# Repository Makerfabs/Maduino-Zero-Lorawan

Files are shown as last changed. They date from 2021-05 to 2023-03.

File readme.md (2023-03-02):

# Maduino Zero Lorawan

```c++
/*
Version:		V1.3
Author:			Vincent
Create Date:	2021/5/19
Note:
		V2.0:Change for Ra08
		V1.3:Change Wiki Link
		V1.2:Add Maduino Zero Lorawan Change Frequence.docx
		V1.1:Add At command explain.
*/
```



[toc]

# Makerfabs

[Makerfabs home page](https://www.makerfabs.com/)

[Makerfabs Wiki](https://wiki.makerfabs.com/)

# Maduino Zero Lorawan
## Intruduce

Product Link ：[Maduino Zero LoRaWAN](https://www.makerfabs.com/maduino-zero-lorawan.html) 

Wiki Link :  [Maduino Zero LoRaWAN Node](http://wiki.makerfabs.com/Maduino_Zero_LoRaWAN_Node.html) 

Maduino Zero LoRaWan is a solution based on ATSAMD21G18 MCU and LoRaWAN module Ra-08H. The LoRaWAN module Ra-08H is based on the ASR6501 chip, it integrated the LoRa radio transceiver, LoRa modem, and 32-bit RISC MCU, to support LoRa modulation mode and (G) FSK modulation mode. Maduino LoRaWan acts as a LoRaWAN node to transmit/receive the local data to the network by connecting LoRaWAN Gateway. With this module, users are easy to prototype LoRaWAN projects easily in few hours.

## Feature

- ATSAMD21G18, 32-Bit ARM Cortex M0+
- Interface: I2C/SPI/UART/18*GPIO
- With super anti-interference ability, it can work normally in complex interference environment.
- Minimum receiving sensitivity: -137dBm (SF=12/BW=125KHz)
- Maximum transmit power +21dBm
- Working frequency: (Ra-07) 410mhz ~ 525mhz (default), (Ra-07h) 803mhz ~ 930mhz (default)
- Power supply voltage input: 3.3V
- Transmitting working current: 107mA (full load power consumption)
- Receive working current: 6mA
- Sleep current: 3uA

### Front:

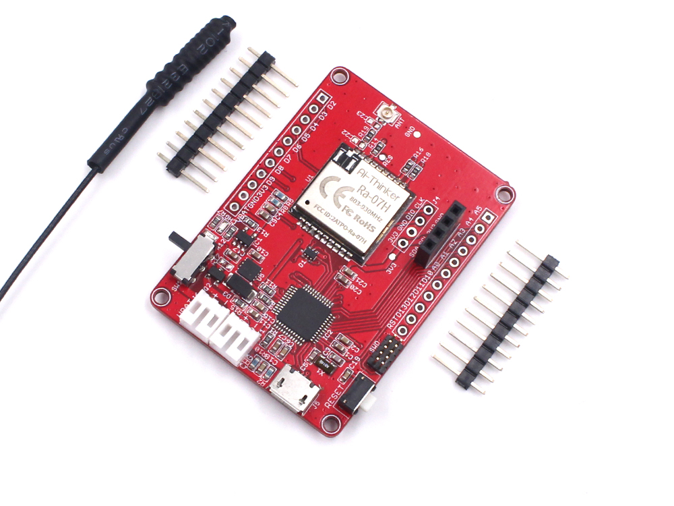
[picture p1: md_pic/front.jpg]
front


### Back:
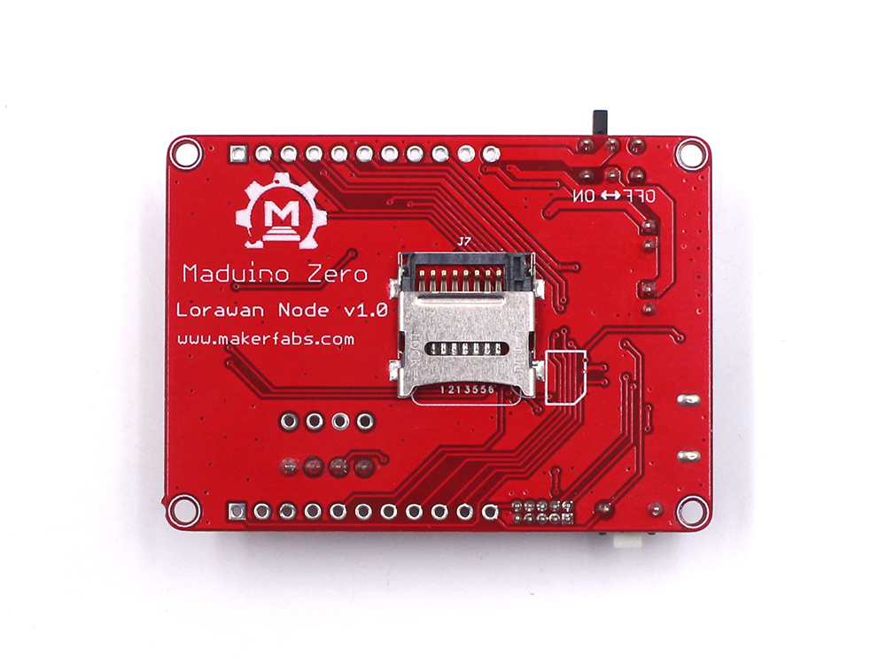
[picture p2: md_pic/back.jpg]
back


# Example

## V2.0 Change Frequence

The module supports 868MHz and 915MHz Lorawan communication, but requires upload different firmware.

**You must need  Makerfabs Down tools or USB to TTL tools**

[MakerFabs CP2104 USB2UART](https://www.makerfabs.com/cp2104-usb-to-serial-converter.html)

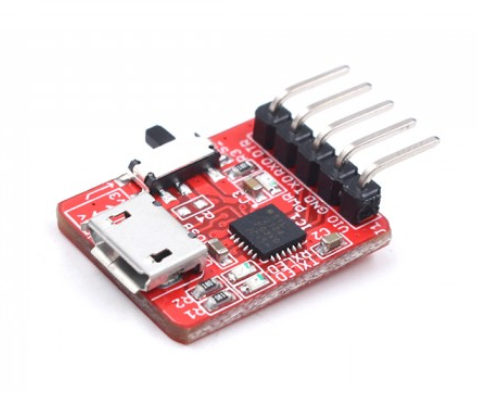
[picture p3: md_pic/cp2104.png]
cp2104


1, Open firmware_update_tool/ TremoProgrammer_v0.8.exe

2, Select firmware you need.

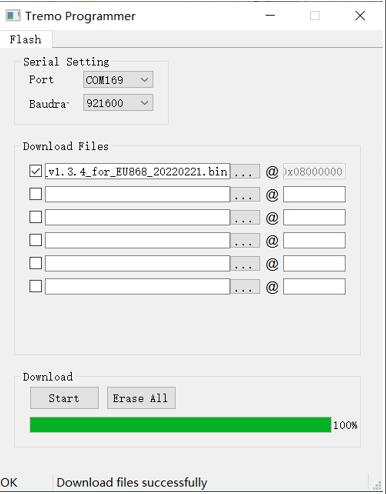
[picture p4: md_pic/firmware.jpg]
firmware


3, Connect MakerFabs CP2104 USB2UART to Maduino Zero Lorawan.

| USB2UART | Maduino Zero Lorawan |
| --- | --- |
| VCC | 3.3V |
| GND | GND |
| TX | CLK |
| RX | DIO |

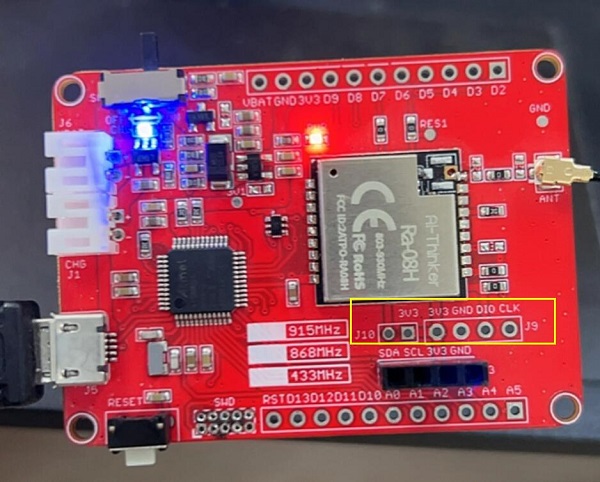
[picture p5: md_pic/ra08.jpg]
ra08


4, Connect J10 and 3V3 with a wire

5, Click Download

6, Press RESET button on Maduino

7, Wait download over

## Compiler Options
**If you have any questions，such as how to install the development board, how to download the code, how to install the library. Please refer to :[Makerfabs_FAQ](https://github.com/Makerfabs/Makerfabs_FAQ)**

- Install library : DHT_sensor_library.
- Upload codes, select "Arduino Zero" and "Native USB"

## Example List

### at-test

Simple at command test demo

### at-test-lorawan

Register the Lorawan gateway in OTA mode and send data to the TTN. And send message to ThingSpeak.
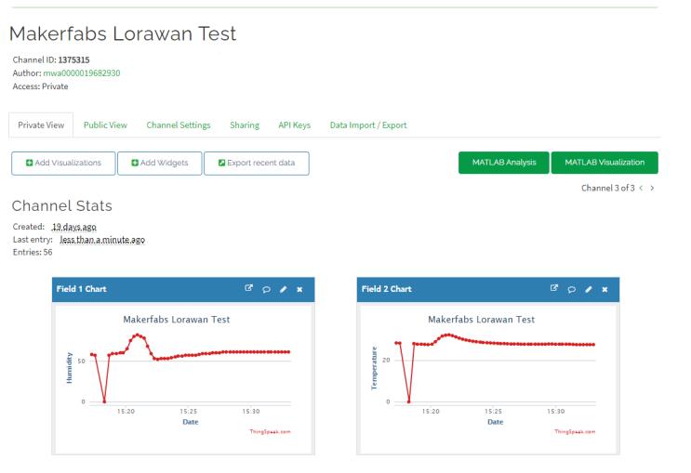
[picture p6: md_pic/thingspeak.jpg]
thingspeak


### test_SD

Simple SD card test for read and write.

### downlink_control

Using TTN console send a download message to Maduino. 

## AT Command Explain

### AT+CDEVEUI?

*Inquire DEVEUI right now.*

AT+CDEVEUI?

### AT+CDEVEUI=&lt;DevEUI&gt;

*Set DEVEUI, APPEUI and APPKEY.*

AT+CDEVEUI=&lt;DevEUI:length is 16&gt;
AT+CAPPEUI=&lt;AppEUI:length is 16&gt;
AT+CAPPKEY=&lt;AppKey:length is 32&gt;

OTAA join mode need these three numbers.

### AT+CJOINMODE=&lt;MODE&gt;

*Set join mode via OTAA.*

AT+CJOINMODE=&lt;MODE&gt;
&lt;MODE&gt;
0：OTAA
1：ABP
Defualt mode is OTAA.

AT+CJOINMODE=0

### AT+CCLASS=&lt;MODE&gt;

*Set lorwan mode.*

AT+CJOINMODE=&lt;MODE&gt;
&lt;MODE&gt;
0：ClassA
1：ClassB
2：ClassC

Defualt mode is ClassA.

AT+CCLASS=0

### AT+CJOIN=&lt;ParaValue1&gt;,[ParaValue2],…[ParaValue4]

*Join Lorawan to Lorawan webgate.*

AT+CJOIN=&lt;ParaValue1&gt;,[ParaValue2],…[ParaValue4]

&lt;ParaTag1&gt;

0: Stop JOIN
1: Start JOIN

[ParaValue2]

0: Disable Auto JOIN
1: Enable Auto JOIN

[ParaValue3]

JOIN cycle,range 7 to 255, unit is second。
Default value is 8.

[ParaValue4]

Maximum number of access attempts,range 1 to 256.

AT+CJOIN=1,0,10,1
Set JOIN parameter: Start join, disable automatic join, try period is 10s, maximum attempt times is 8.

### AT+DTRX=[confirm],[nbtrials],&lt;Length&gt;,&lt;Payload&gt;

*Send one message to webgate,and receive message.*

AT+DTRX=[confirm],[nbtrials],&lt;Length&gt;,&lt;Payload&gt;

[confirm]

0: UnConfirmed up message

1: Confirmed up message

[nbtrials]

Set sending times.
Confirm and nbtrials refer to the corresponding AT instruction, valid for this dispatch only, optional.

&lt;Length&gt;

Represents the number of strings. The maximum value is specified in the access specification. 
The length of bytes allowed to be transmitted is different at different rates (see the Lorawan protocol for details). 
0 indicates that empty packets are sent.

&lt;Payload&gt;

Hexadecimal (2 characters for 1 number)

AT+DTRX=1,2,5,0123456789

OK+SEND:05

OK+SENT:01

OK+RECV:02,01,00

Confirm data sent successfully, valid data received by server should be 0x01 0x23 0x45 0x67 0x89.
And received downlink confirmation 0x02,0x01,0x00.

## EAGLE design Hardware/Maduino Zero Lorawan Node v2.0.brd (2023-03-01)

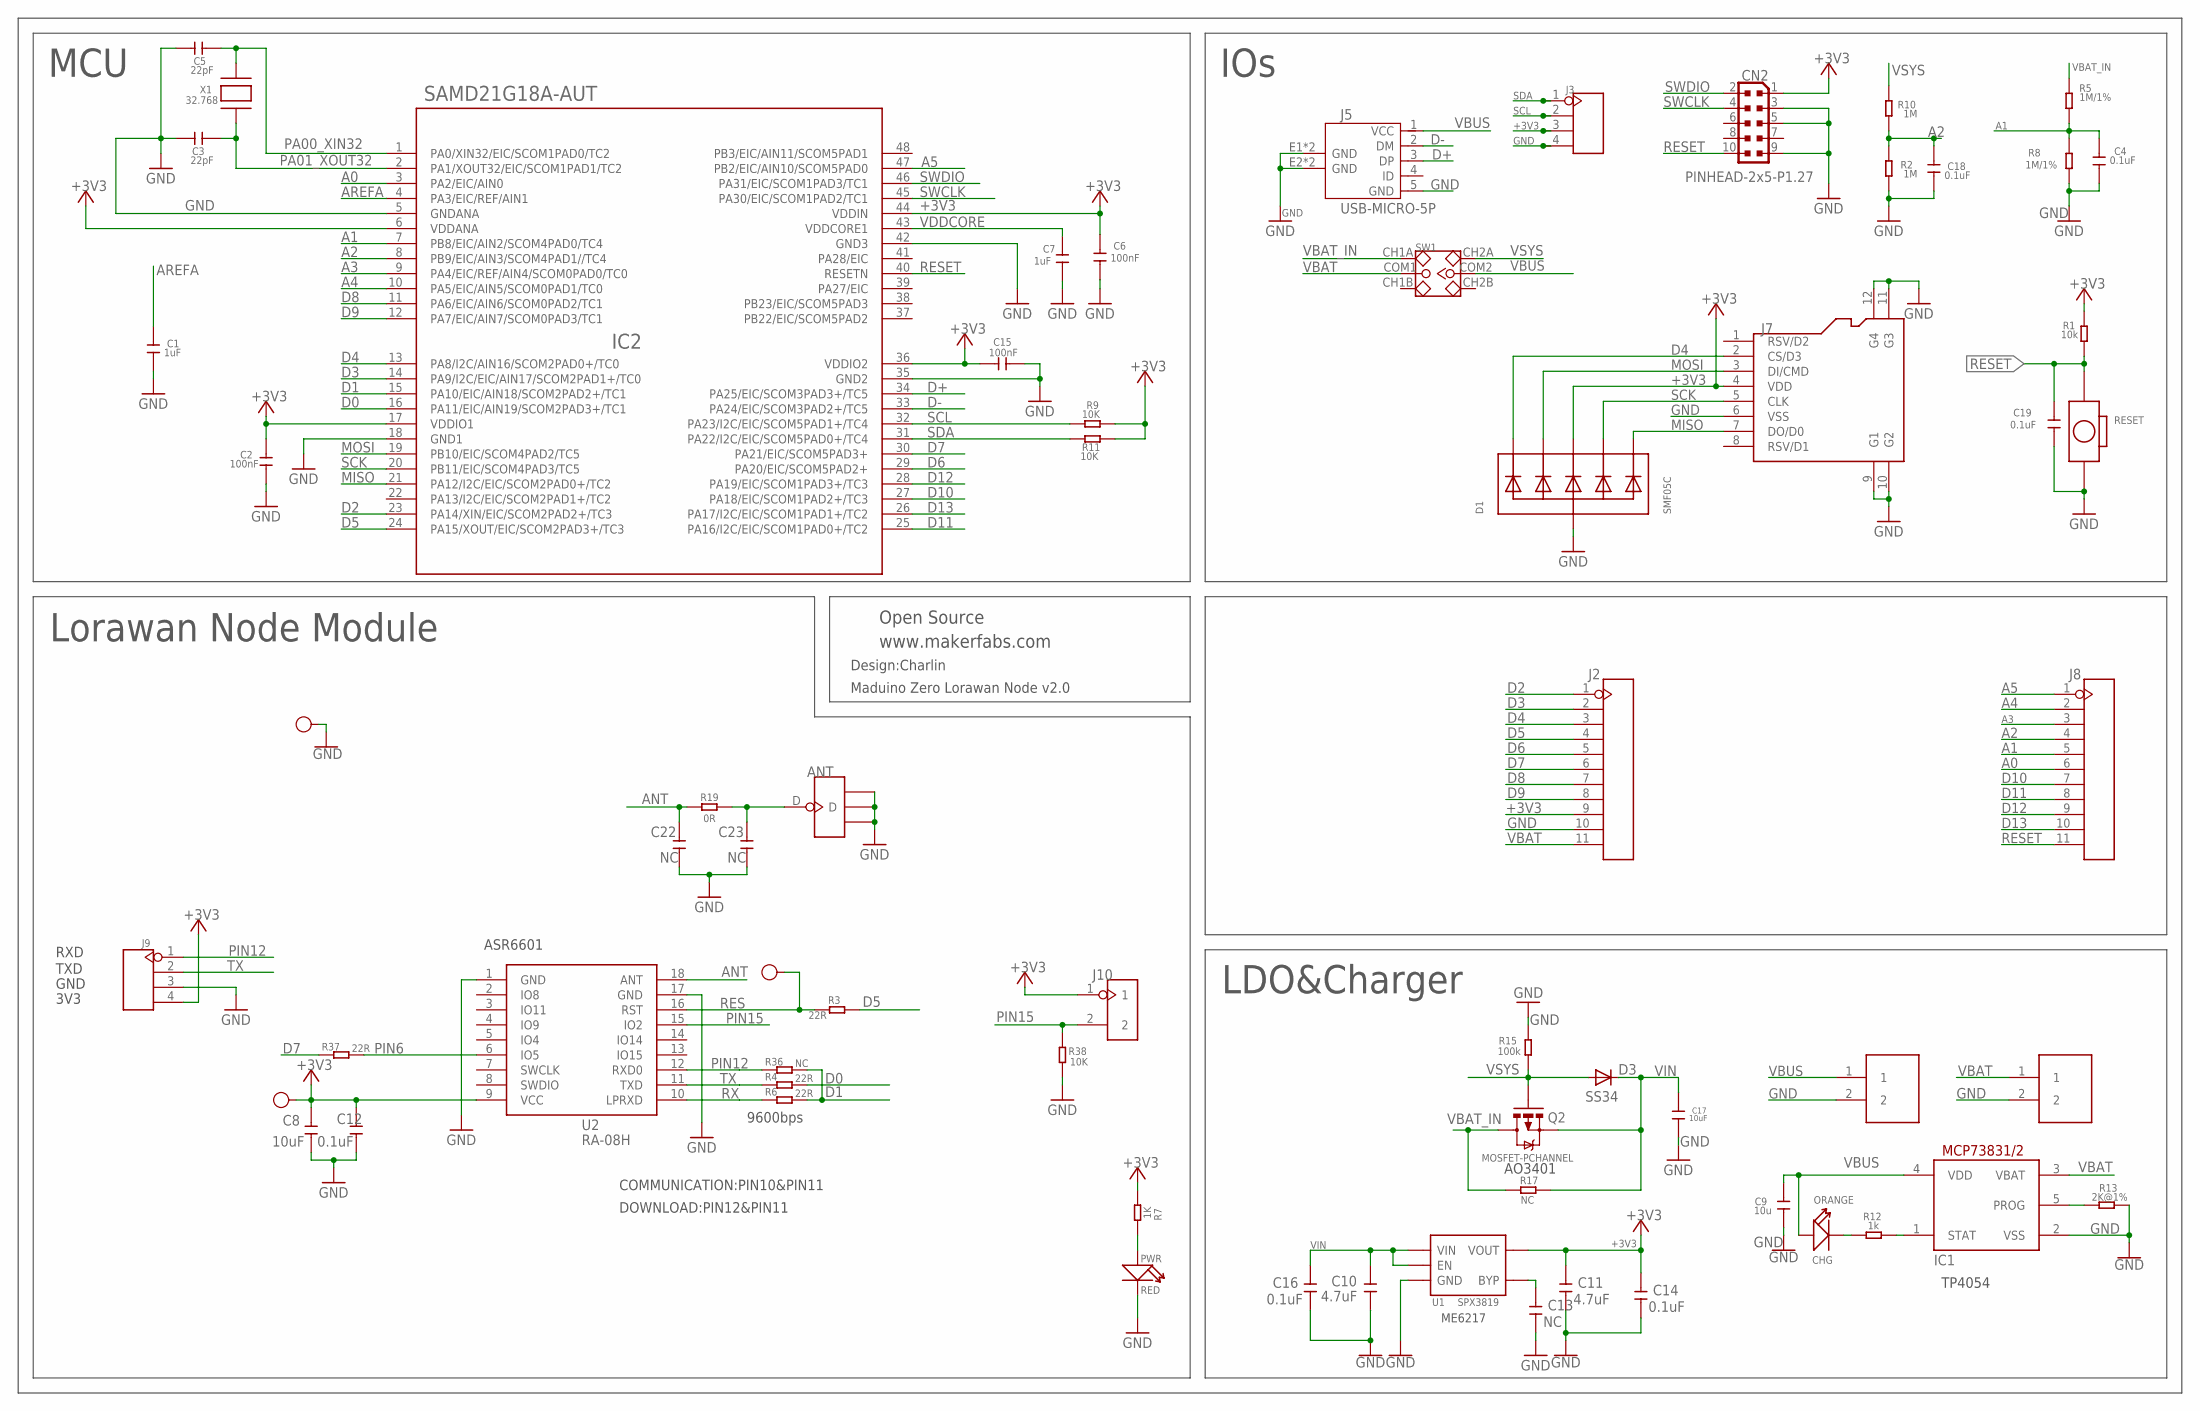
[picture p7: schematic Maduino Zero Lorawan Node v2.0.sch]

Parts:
3V3: TEST-POINT'4545'; TP-D45MIL; PARTNO DNP
ANT: ANTENNA-U-FL; 4P-U-FL
C1, C7: 1uF; 0603
C2, C6, C15: 100nF; 0603
C3, C5: 22pF; 0603
C4, C12, C14, C16, C18, C19: 0.1uF; 0603
C8, C17: 10uF; 0603
C9: 10u; 0603
C10, C11: 4.7uF; 0603
C13, C22, C23: NC; 0603
CHG: ORANGE; D0603
CN2: PINHEAD-2x5-P1.27; PINHEAD_2X05_127
D1: SMF05C; SOT363
D3: SS34; DO-214AC
GND: TEST-POINT'4545'; TP-D45MIL
IC1: MCP73831/OT; SOT23-5L
IC2: SAMD21G18A-AUT; TQFP48-7X7
J1, J6: PH2.0-2P-90-DIP
J2, J8: HEADER-11P-2.54; 11P-2.54
J3, J9: HEADER-4P-60/35MILROUND; 4P-65/35ROUND
J5: USB-MICRO-5P; MICRO-USB-5P
J7: HOLDER-MICROSD-8P; 8P-SMD
J10: HEADER-2P-2.0; 2P-2.0
PWR: RED; LED-0603
Q2: MOSFET-PCHANNEL; SOT23-3
R1: 10k; R0603
R2, R10: 1M; R0603
R3, R4, R6, R37: 22R; R0603
R5, R8: 1M/1%; R0603
R7: 1K; R0603
R9, R11, R38: 10K; R0603
R12: 1k; R0603
R13: 2K@1%; R0603
R15: 100k; R0603
R17, R36: NC; R0603
R19: 0R; R0603
RESET: BOTTON-2P-90D; 2P-7.62X3.56-90D
RST: TEST-POINT'4545'; TP-D45MIL; PARTNO DNP
SW1: SWITCH-2CH-6P; 6P-2CH-2.54-7.6X3.0
U1: SPX3819; SOT23-5
U2: RA-08H
X1: 32.768; XTAL3215

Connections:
+3V3: 3V3.T, C2.2, C6.1, C8.2, C11.2, C12.2, C14.2, C15.1, CN2.1, D1.4 (C3), IC2.6 (VDDANA), IC2.17 (VDDIO1), IC2.36 (VDDIO2), IC2.44 (VDDIN), J2.9, J3.3, J7.4 (VDD), J9.4, J10.1, R1.2, R7.1, R9.2, R11.2, U1.5 (VOUT), U2.9 (VCC)
A0: IC2.3 (PA2/EIC/AIN0), J8.6
A1: C4.1, IC2.7 (PB8/EIC/AIN2/SCOM4PAD0/TC4), J8.5, R5.1, R8.2
A2: C18.1, IC2.8 (PB9/EIC/AIN3/SCOM4PAD1//TC4), J8.4, R2.2, R10.1
A3: IC2.9 (PA4/EIC/REF/AIN4/SCOM0PAD0/TC0), J8.3
A4: IC2.10 (PA5/EIC/AIN5/SCOM0PAD1/TC0), J8.2
A5: IC2.47 (PB2/EIC/AIN10/SCOM5PAD0), J8.1
ANT: C22.2, R19.1, U2.18 (ANT)
AREFA: C1.1, IC2.4 (PA3/EIC/REF/AIN1)
D0: IC2.16 (PA11/EIC/AIN19/SCOM2PAD3+/TC1), R4.2
D1: IC2.15 (PA10/EIC/AIN18/SCOM2PAD2+/TC1), R6.2, R36.2
D2: IC2.23 (PA14/XIN/EIC/SCOM2PAD2+/TC3), J2.1
D3: IC2.14 (PA9/I2C/EIC/AIN17/SCOM2PAD1+/TC0), J2.2
D4: D1.1 (C1), IC2.13 (PA8/I2C/AIN16/SCOM2PAD0+/TC0), J2.3, J7.2 (CS/D3)
D5: IC2.24 (PA15/XOUT/EIC/SCOM2PAD3+/TC3), J2.4, R3.2
D6: IC2.29 (PA20/EIC/SCOM5PAD2+), J2.5
D7: IC2.30 (PA21/EIC/SCOM5PAD3+), J2.6, R37.1
D8: IC2.11 (PA6/EIC/AIN6/SCOM0PAD2/TC1), J2.7
D9: IC2.12 (PA7/EIC/AIN7/SCOM0PAD3/TC1), J2.8
D10: IC2.27 (PA18/EIC/SCOM1PAD2+/TC3), J8.7
D11: IC2.25 (PA16/I2C/EIC/SCOM1PAD0+/TC2), J8.8
D12: IC2.28 (PA19/EIC/SCOM1PAD3+/TC3), J8.9
D13: IC2.26 (PA17/I2C/EIC/SCOM1PAD1+/TC2), J8.10
D+: IC2.34 (PA25/EIC/SCOM3PAD3+/TC5), J5.3 (DP)
D-: IC2.33 (PA24/EIC/SCOM3PAD2+/TC5), J5.2 (DM)
GND: ANT.GND1, ANT.GND2, ANT.GND3, C1.2, C2.1, C3.2, C4.2, C5.2, C6.2, C7.2, C8.1, C9.1, C10.1, C11.1, C12.1, C13.1, C14.1, C15.2, C16.1, C17.1, C18.2, C19.1, C22.1, C23.1, CN2.3, CN2.5, CN2.9, D1.2 (A), GND.T, IC1.2 (VSS), IC2.5 (GNDANA), IC2.18 (GND1), IC2.35 (GND2), IC2.42 (GND3), J1.2, J2.10, J3.4, J5.5 (GND), J5.E1 (GND), J5.E2 (GND), J5.P1 (GND), J5.P2 (GND), J6.2, J7.6 (VSS), J7.9 (G1), J7.10 (G2), J7.11 (G3), J7.12 (G4), J9.3, PWR.-, R2.1, R8.1, R13.2, R15.2, R38.2, RESET.P$2 (2), U1.2 (GND), U2.1 (GND), U2.17 (GND)
MISO: D1.6 (C5), IC2.21 (PA12/I2C/EIC/SCOM2PAD0+/TC2), J7.7 (DO/D0)
MOSI: D1.3 (C2), IC2.19 (PB10/EIC/SCOM4PAD2/TC5), J7.3 (DI/CMD)
unnamed: PWR.+, R7.2
unnamed: ANT.D, C23.2, R19.2
unnamed: CHG.-, R12.1
unnamed: IC1.1 (STAT), R12.2
unnamed: IC1.5 (PROG), R13.1
unnamed: C13.2, U1.4 (BYP)
PA00_XIN32: C5.1, IC2.1 (PA0/XIN32/EIC/SCOM1PAD0/TC2), X1.P$2
PA01_XOUT32: C3.1, IC2.2 (PA1/XOUT32/EIC/SCOM1PAD1/TC2), X1.P$1
PIN6: R37.2, U2.6 (IO5)
PIN12: J9.1, R36.1, U2.12 (RXD0)
PIN15: J10.2, R38.1, U2.15 (IO2)
RES: R3.1, RST.T, U2.16 (RST)
RESET: C19.2, CN2.10, IC2.40 (RESETN), J8.11, R1.1, RESET.P$1 (1)
RX: R6.1, U2.10 (LPRXD)
SCK: D1.5 (C4), IC2.20 (PB11/EIC/SCOM4PAD3/TC5), J7.5 (CLK)
SCL: IC2.32 (PA23/I2C/EIC/SCOM5PAD1+/TC4), J3.2, R9.1
SDA: IC2.31 (PA22/I2C/EIC/SCOM5PAD0+/TC4), J3.1, R11.1
SWCLK: CN2.4, IC2.45 (PA30/EIC/SCOM1PAD2/TC1)
SWDIO: CN2.2, IC2.46 (PA31/EIC/SCOM1PAD3/TC1)
TX: J9.2, R4.1, U2.11 (TXD)
VBAT: IC1.3 (VBAT), J2.11, J6.1, SW1.COM1
VBAT_IN: Q2.3 (D), R5.2, R17.1, SW1.CH1A
VBUS: C9.2, CHG.+, IC1.4 (VDD), J1.1, J5.1 (VCC), SW1.COM2
VDDCORE: C7.1, IC2.43 (VDDCORE1)
VIN: C10.2, C16.2, C17.2, D3.C, Q2.2 (S), R17.2, U1.1 (VIN), U1.3 (EN)
VSYS: D3.A, Q2.1 (G), R10.2, R15.1, SW1.CH2A

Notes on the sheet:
Lorawan Node Module
www.makerfabs.com
MCU
IOs
LDO&Charger
Design:Charlin
Open Source
AO3401
Maduino Zero Lorawan Node v2.0
ASR6601
COMMUNICATION:PIN10&PIN11
DOWNLOAD:PIN12&PIN11
9600bps
RXD
TXD
GND
3V3
ME6217
TP4054

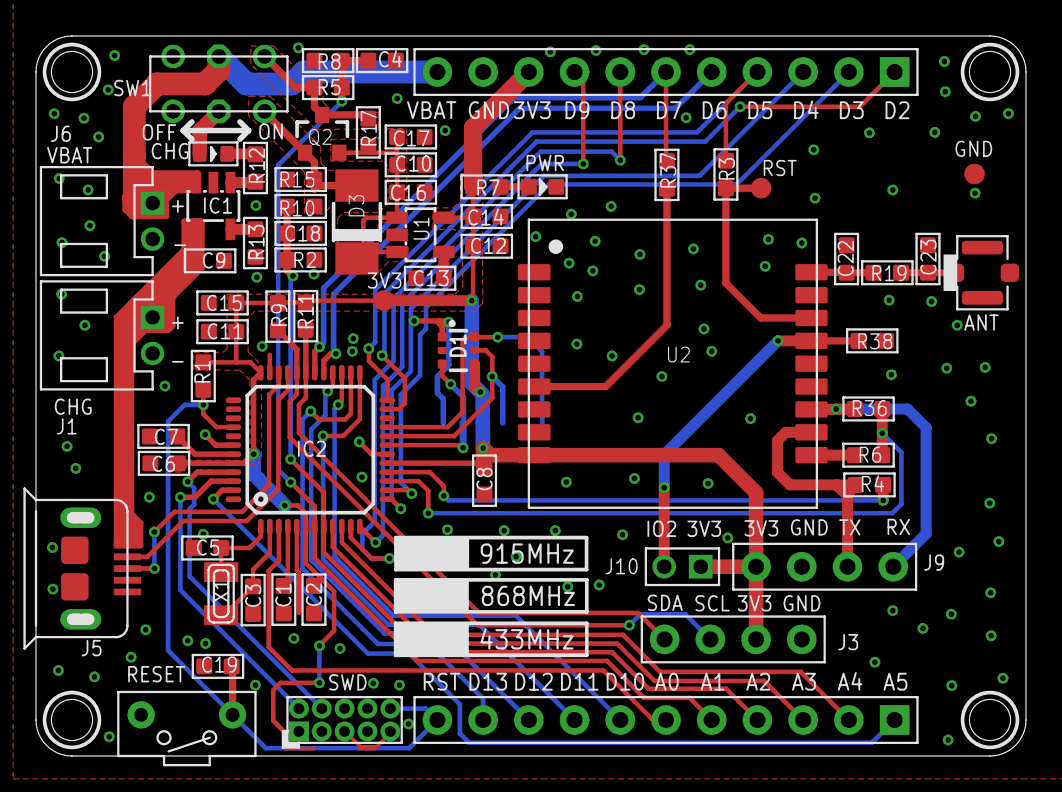
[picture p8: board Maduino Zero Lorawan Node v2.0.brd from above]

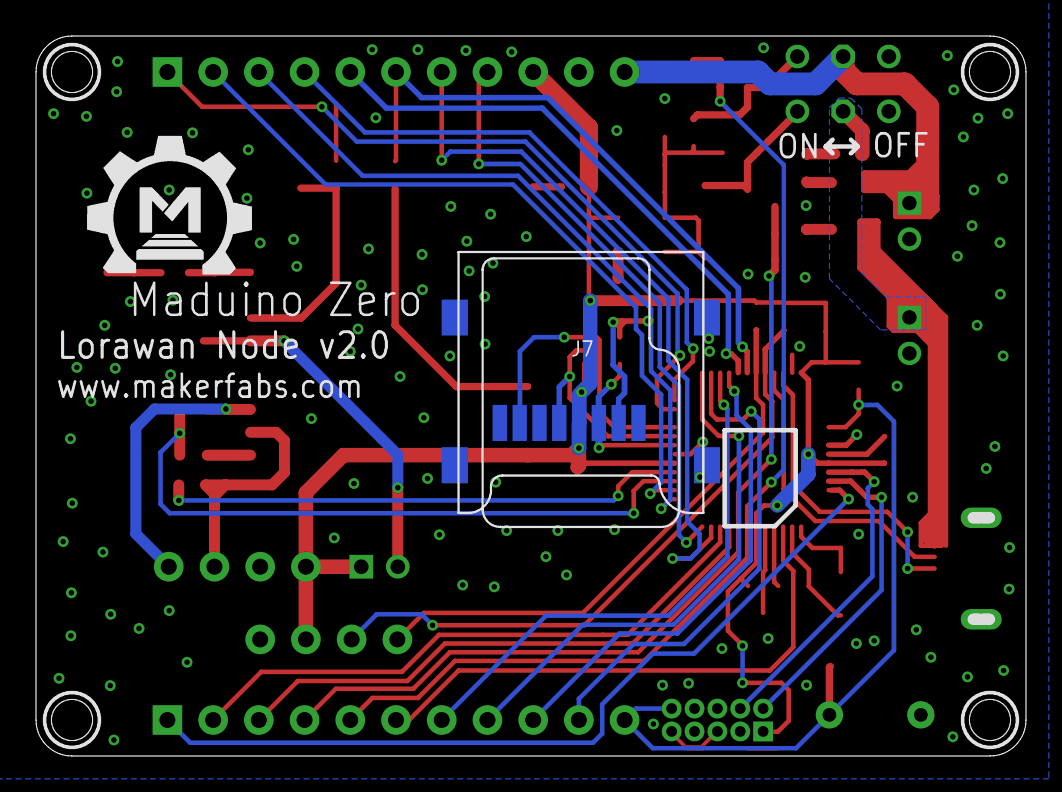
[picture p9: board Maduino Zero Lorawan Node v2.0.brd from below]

Board: 2 copper layers, 55.0 x 40.0 mm, 67 parts (2 on the bottom side), 54 nets.

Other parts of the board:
U$1: MAKERFABS_0.3

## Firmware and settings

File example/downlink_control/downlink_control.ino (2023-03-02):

#include <stdio.h>
#include <string.h>
#include <Wire.h>
#include <Adafruit_GFX.h>
#include <Adafruit_SSD1306.h>

#define DEBUG true

// get appeui and appkey from the thing network
#define DEVEUI "UES YOUR DEVEUI"
#define APPEUI "UES YOUR APPEUI"
#define APPKEY "UES YOUR APPKEY"

#define PWR_KEY 9
#define RST_KEY 6
#define LOW_PWR_KEY 5

#define SCREEN_WIDTH 128 // OLED display width, in pixels
#define SCREEN_HEIGHT 32 // OLED display height, in pixels
#define OLED_RESET -1    // Reset pin # (or -1 if sharing Arduino reset pin)

Adafruit_SSD1306 display(SCREEN_WIDTH, SCREEN_HEIGHT, &Wire, OLED_RESET);
int led_flag = 0;

void setup()
{
    Serial1.begin(9600);
    SerialUSB.begin(9600);
    Wire.begin();
    oled_init();

    SerialUSB.println("Now turnning the Lorawan on.Please wait.");

    pin_init();
    SerialUSB.println("Init over");

    sendData("AT+CDEVEUI=" + String(DEVEUI), 3000, DEBUG);
    sendData("AT+CAPPEUI=" + String(APPEUI), 3000, DEBUG);
    sendData("AT+CAPPKEY=" + String(APPKEY), 3000, DEBUG);
    sendData("AT+CJOINMODE=0", 3000, DEBUG);
    sendData("AT+CCLASS=0", 30000, DEBUG);
    sendData("AT+CJOIN=1,0,8,8", 30000, DEBUG);
}

long int runtime = 20000;
void loop()
{
    if ((millis() - runtime) > 10000)
    {

        String downlink = "";
        if (led_flag == 1)
            downlink = lorawan_tx_rx("F8", 20000);
        if (led_flag == 0)
            downlink = lorawan_tx_rx("F7", 20000);

        if (downlink.endsWith("F8"))
            led_flag = 1;
        if (downlink.endsWith("F7"))
            led_flag = 0;

        display.clearDisplay();
        display.setCursor(0, 4);
        display.println(downlink);
        if (led_flag == 1)
        {
            display.setCursor(0, 20);
            display.println("LED ON");
        }
        else
        {
            display.setCursor(0, 20);
            display.println("LED OFF");
        }

        display.display();

        runtime = millis();
    }
    while (Serial1.available() > 0)
    {
        SerialUSB.write(Serial1.read());
        yield();
    }
}

void pin_init()
{
    pinMode(PWR_KEY, OUTPUT);
    pinMode(RST_KEY, OUTPUT);
    pinMode(LOW_PWR_KEY, OUTPUT);

    digitalWrite(RST_KEY, LOW);
    digitalWrite(LOW_PWR_KEY, HIGH);
    digitalWrite(PWR_KEY, HIGH);

    digitalWrite(PWR_KEY, LOW);
    delay(3000);
    digitalWrite(PWR_KEY, HIGH);
    delay(10000);
}

void oled_init()
{
    if (!display.begin(SSD1306_SWITCHCAPVCC, 0x3C))
    { // Address 0x3C for 128x32
        Serial.println(F("SSD1306 allocation failed"));
        for (;;)
            ; // Don't proceed, loop forever
    }
    Serial.println("SSD1306 found");

    display.clearDisplay();
    display.setTextColor(SSD1306_WHITE);
    display.setTextSize(1); // Draw 2X-scale text
    display.setCursor(0, 4);
    display.println("Makerfabs Lorawan");
    display.setCursor(0, 20);
    display.println("Dowlink demo");
    display.display();
}

String sendData(String command, const int timeout, boolean debug)
{
    String response = "";
    Serial1.println(command);
    long int time = millis();
    while ((time + timeout) > millis())
    {
        while (Serial1.available())
        {
            char c = Serial1.read();
            response += c;
        }
    }
    if (debug)
    {
        SerialUSB.print(response);
    }
    return response;
}

String lorawan_tx_rx(String msg_hex, const int timeout)
{
    String response = "";
    String rec_head = "OK+RECV:";

    char msg[50] = "";
    sprintf(msg, "AT+DTRX=1,2,5,%s", msg_hex.c_str());

    SerialUSB.println(msg);
    Serial1.println(msg);

    long int time = millis();
    while ((time + timeout) > millis())
    {
        while (Serial1.available())
        {
            char c = Serial1.read();

            if (c == '\r')
                continue;
            else if (c == '\n')
            {
                SerialUSB.println(response);
                
                if (response.indexOf(rec_head) != -1)
                {
                    SerialUSB.println("-----------Get downlink msg-----------");

                    String result = response.substring(response.indexOf(rec_head) + rec_head.length());

                    SerialUSB.println(result);
                    SerialUSB.println("-----------Over-----------");
                    return result;
                }
                else if (response.indexOf("ERR+SENT") != -1)
                {
                    SerialUSB.println("-----------Get downlink msg-----------");

                    String result = "SEND FAILED";

                    SerialUSB.println(result);
                    SerialUSB.println("-----------Over-----------");
                    return result;
                }

                response = "";
            }
            else
                response += c;
        }
    }
    SerialUSB.println(response);

    return "";
}

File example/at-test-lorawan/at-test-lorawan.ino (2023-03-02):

#include <stdio.h>
#include <string.h>
#include "DHT.h"

#define DEBUG true

//get appeui and appkey from the thing network
#define DEVEUI "UES YOUR DEVEUI"
#define APPEUI "UES YOUR APPEUI"
#define APPKEY "UES YOUR APPKEY"

#define DHTPIN 7      // Digital pin connected to the DHT sensor
#define DHTTYPE DHT11 // DHT 11

DHT dht(DHTPIN, DHTTYPE);

int PWR_KEY = 9;
int RST_KEY = 6;
int LOW_PWR_KEY = 5;

bool ModuleState = false;
long int runtime = 20000;

void setup()
{

    Serial1.begin(9600);
    SerialUSB.begin(9600);

    dht.begin();

    SerialUSB.println("Now turnning the Lorawan on.Please wait.");

    pin_init();
    SerialUSB.println("Init over");

    //set DEVEUI
    //sendData("AT+CDEVEUI?", 3000, DEBUG);
    sendData("AT+CDEVEUI=" + String(DEVEUI), 3000, DEBUG);

    //set APPEUI and APPKEY
    sendData("AT+CAPPEUI=" + String(APPEUI), 3000, DEBUG);
    sendData("AT+CAPPKEY=" + String(APPKEY), 3000, DEBUG);

    //set join mod "OTAA"
    sendData("AT+CJOINMODE=0", 3000, DEBUG);

    //join lorawan
    sendData("AT+CCLASS=0", 30000, DEBUG);

    //join lorawan
    sendData("AT+CJOIN=1,0,10,1", 30000, DEBUG);

    //set one message to webgate
    //AT+DTRX=1,2,10,4D414B455246414253
    //sendData("AT+DTRX=1,2,5,FF 00 88", 3000, DEBUG);
}

void loop()
{
    if (runtime - millis() > 10000)
    {
        float h = dht.readHumidity();
        float t = dht.readTemperature();
        int hum = (int)(h);
        int temp = (int)(t * 10);
        char msg[30] = "";
        sprintf(msg, "AT+DTRX=1,2,5,%02x%04x", hum, temp);
        SerialUSB.println(msg);
        sendData((String)msg, 3000, DEBUG);

        runtime = millis();
    }
    while (Serial1.available() > 0)
    {
        SerialUSB.write(Serial1.read());
        yield();
    }
    while (SerialUSB.available() > 0)
    {
        Serial1.write(SerialUSB.read());
        yield();
    }
}

void pin_init()
{
    pinMode(PWR_KEY, OUTPUT);
    pinMode(RST_KEY, OUTPUT);
    pinMode(LOW_PWR_KEY, OUTPUT);

    digitalWrite(RST_KEY, LOW);
    digitalWrite(LOW_PWR_KEY, HIGH);
    digitalWrite(PWR_KEY, HIGH);

    digitalWrite(PWR_KEY, LOW);
    delay(3000);
    digitalWrite(PWR_KEY, HIGH);
    delay(10000);
}

String sendData(String command, const int timeout, boolean debug)
{
    String response = "";
    Serial1.println(command);
    long int time = millis();
    while ((time + timeout) > millis())
    {
        while (Serial1.available())
        {
            char c = Serial1.read();
            response += c;
        }
    }
    if (debug)
    {
        SerialUSB.print(response);
    }
    return response;
}

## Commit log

2021-05-22 create hardware
    [Maduino Zero Lorawan Node v1.0.brd, Maduino Zero Lorawan Node v1.0.sch]
2023-03-01 Hardware update
    [Maduino Zero Lorawan Node v1.0.brd, Maduino Zero Lorawan Node v1.0.sch, Maduino Zero Lorawan Node v2.0.brd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]

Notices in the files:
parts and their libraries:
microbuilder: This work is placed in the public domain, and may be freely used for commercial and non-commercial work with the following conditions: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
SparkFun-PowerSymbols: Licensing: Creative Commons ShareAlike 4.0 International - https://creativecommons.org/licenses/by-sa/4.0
